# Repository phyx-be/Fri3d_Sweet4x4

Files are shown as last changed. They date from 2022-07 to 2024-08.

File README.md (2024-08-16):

# Sweet4x4 REV02

[Manual on how to assemble can be found here](https://fri3dcamp.github.io/badge_2024/sweet4x4/) Revision `02` no longer requires the Fri3d badge but instead relies solely on the us of a [TNY, QT Py or XIAO board](https://github.com/adafruit/awesome-qt-py). For future workshops we plan to use the [LANA TNY](https://phyx.be/LANA_TNY/). The workshop during [Fri3d Camp](https://fri3d.be/) will be done with a XIAO RP2040. 

## Firmare
LANA_TNY firmware is still underway.
For the Fri3d Camp workshop we opted for RP2040. An example using [KMK](https://kmkfw.io/) can be found in this repository.

There is an issue with the LEDs, when pushed too far in the footprint they tend to break. In order to prevent damaging the LEDs we sugges mounting only 6 on the bottom and use them for underglow.

Fully Assembled board with keycaps and case

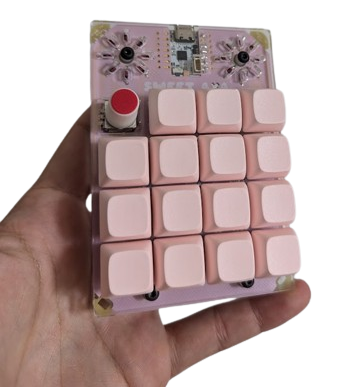
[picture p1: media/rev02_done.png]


# Fri3d_Sweet4x4 REV01

## About
The progress and more details about this project can be found on [Hackaday.io](https://hackaday.io/project/186574-sweet-4x4)

This PCB has, besides the required layout for a 4x4 keypad, some nifty features which will help during assembly and maintenance. The left most corner contains a diode bending corner, making sure that your diodes have their leads bent in the right spot will help during assembly. The other useful feature if a built in lube station. The X cutout will snugly fit a stem whilst the rectangular hole will  fit the body the switch you're cleaning.

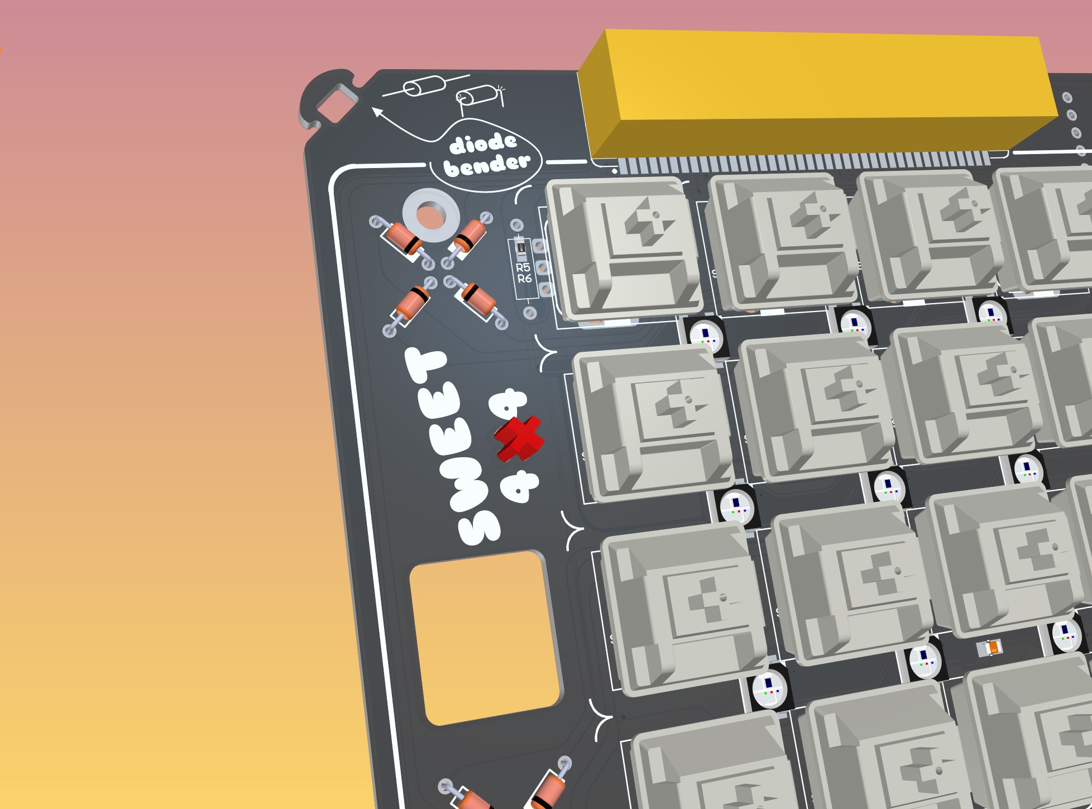
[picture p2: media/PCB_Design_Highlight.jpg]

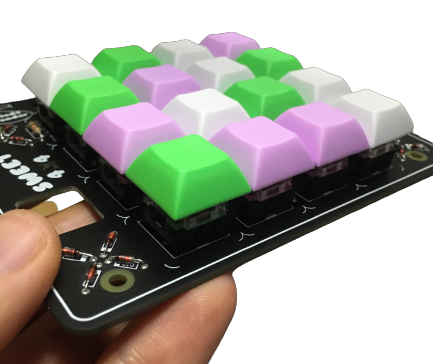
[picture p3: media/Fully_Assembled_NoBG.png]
Fully Assembled board with keycaps

Fully Assembled board with keycaps

## Getting started
### Using the Fri3d Camp 2022 badge
The Fri3d Badge has an ESP32 on board, because of the chip the badge uses we can only create a 4x4 Bluetooth keyboard.
1. Make sure you have Arduino IDE installed
2. Add the ESP32 board to the Arduino board manager, I think this link works well : https://randomnerdtutorials.com/installing-the-esp32-board-in-arduino-ide-windows-instructions/
3. Add the libraries you need
  - BLEKeyboard : https://github.com/T-vK/ESP32-BLE-Keyboard
  - Keypad : https://github.com/Chris--A/Keypad
  - Badge2020 : https://github.com/Fri3dCamp/Badge2020_arduino
  - Neopixel : https://github.com/adafruit/Adafruit_NeoPixel
4. Open the Sweet_4x4_minimal.ino code in the Arduino IDE, this only includes code to turn the pcb + badge into a BLE keyboard (not using screen or RGB leds)
5. Optionally you can use the Sweet_4x4_full.ino code, this also include some basic code to get the TFT screen to work

### Using a XIAO module
This allows to use the 4x4 PCB as a HID device over USB-C
Updating soon

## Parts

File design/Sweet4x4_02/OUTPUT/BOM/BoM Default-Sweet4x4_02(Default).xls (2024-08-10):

Bill of Materials |  |  | Sweet 4x4
Project: |  | Sweet4x4_02.PrjPcb
Revision: |  | 02
Variant: |  | Default
Creation Date: | 21/06/2024 | 14:10
Print Date: | 2024-06-21 | 14:10:08
Footprint | Comment | LibRef | Designator | Value | Description | Supplier 1 | Supplier Part Number 1 | Supplier 2 | Supplier Part Number 2 | Supplier 3 | Supplier Part Number 3 | Quantity
C_5.08mm |  | CAP 100nF 50V 5.08mm | C3, C4, C5 | 100nF 50V | CAP 100nF 50V 5.08mm | LCSC | C84772 |  |  |  |  | 3
DO-35 | 1N4148 100V 200mA 1Vf@10mA | DIO 1N4148 DO-35 | D1, D2, D3, D4, D5, D6, D7, D8, D9, D10, D11, D12, D13, D14, D15, D16 | 1N4148 | DIO 1N4148 DO-35 | LCSC | C14538 | LCSC | C14516 |  |  | 16
LED_5mm_RGB_RECT_EASY | WS2812 based digital RGB LED 5mm Rectangle | LED RGB WS2812 5mm Rectangle | D17, D18, D19, D20, D21, D22, D23, D24, D25 | WS2812D-255 | LED RGB WS2812 5mm Rectangle | LCSC | C4154874 |  |  |  |  | 9
PHYX_LANA_TNY_SMD | CH23V203 based TNY module | MOD # CH23V203 LANA TNY SMD | MOD1 | LANA TNY | MOD # CH23V203 LANA TNY SMD | Phyx | LANA TNY |  |  |  |  | 1
Cherry_MX1A | Cherry MX Blue | SW Cherry MX1A-E1NN Blue | SW1, SW2, SW3, SW4, SW5, SW6, SW7, SW8, SW9, SW10, SW11, SW12, SW13, SW14, SW15, SW16 | MX1A-E1NN | SW Cherry MX1A-E1NN Blue | Digi-key | CH196-ND | Mouser | 540-MX1A-E1NN |  |  | 16
 |  |  |  |  |  |  |  |  |  |  |  | 45
Approved |  | Notes

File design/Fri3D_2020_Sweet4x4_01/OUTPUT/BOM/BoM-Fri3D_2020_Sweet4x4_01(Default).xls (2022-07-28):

Bill of Materials |  |  | Fri3D 2020 Sweet 4x4
Project: |  | Fri3D_2020_Sweet4x4_01.PrjPcb
Revision: |  | 01
Variant: |  | Default
Creation Date: | 07/06/2022 | 22:18
Print Date: | 2022-06-07 | 22:18:32
Footprint | Comment | LibRef | Designator | Value | Description | Supplier 1 | Supplier Part Number 1 | Supplier 2 | Supplier Part Number 2 | Supplier 3 | Supplier Part Number 3 | Quantity
C0805_N |  | CAP # 10uF 10V 0805 | C1 | 10uF 10V | CAP # 10uF 10V 0805 | Farnell | 2320859 | LCSC | C17024 | Generic | 10uF 10V 0805 X7R | 1
DO-35 | 1N4148 100V 200mA 1Vf@10mA | DIO 1N4148 DO-35 | D1, D2, D3, D4, D5, D6, D7, D8, D9, D10, D11, D12, D13, D14, D15, D16 | 1N4148 | DIO 1N4148 DO-35 | LCSC | C14538 | LCSC | C14516 |  |  | 16
LED_5050_WS2812B_BLACK | WS2812 based digital RGB LED 5050 Black package | LED # RGB WS2812B-5050 BL | D17, D18, D19, D20, D21, D22, D23, D24, D25 | WS218B 5050 BL | LED # RGB WS2812B-5050 BL | Aliexpress | WS2812B Black 5050 | LCSC | C114586 |  |  | 9
MicroBIT_CYLCONN_SMD_180 | MicroBit 180deg connector Cylconn | MicroBit # Cylconn | P2 |  | MicroBit # Cylconn | TaoBao |  |  |  |  |  | 1
R0603_N |  | RES # 10K 0603 | R1, R3, R5 | 10K | RES # 10K 0603 | Farnell | 2502397 | LCSC | C25804 | Generic | 10K 1% 0603 | 3
Cherry_MX1A | Cherry MX Blue | SW Cherry MX1A-E1NN Blue | SW1, SW2, SW3, SW4, SW5, SW6, SW7, SW8, SW9, SW10, SW11, SW12, SW13, SW14, SW15, SW16 | MX1A-E1NN | SW Cherry MX1A-E1NN Blue | Digi-key | CH196-ND | Mouser | 540-MX1A-E1NN |  |  | 16
TP_1.5mm_0.9mm |  | TP 1.5mm | TP1, TP2, TP3, TP4, TP5, TP6, TP7, TP8, TP9, TP10, TP11, TP12, TP13 | NO BOM | TP 1.5mm |  |  |  |  |  |  | 13
 |  |  |  |  |  |  |  |  |  |  |  | 59
Approved |  | Notes

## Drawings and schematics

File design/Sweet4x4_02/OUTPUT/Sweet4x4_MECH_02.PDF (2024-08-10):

## Sweet 4x4 Mechanical drawings

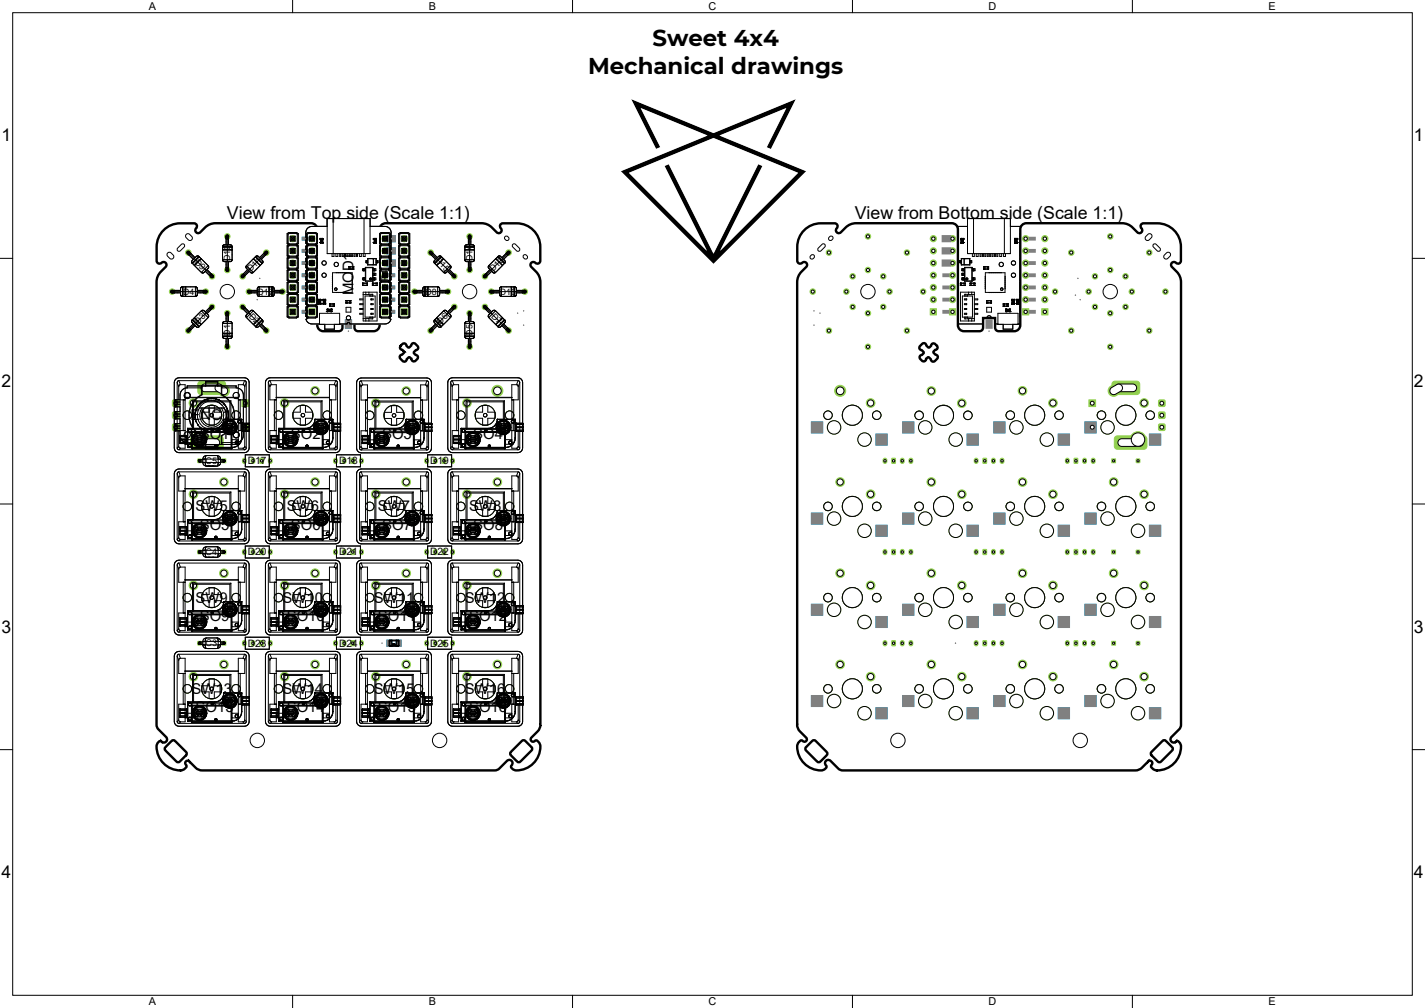
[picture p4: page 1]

## Sweet 4x4 Silkscreen

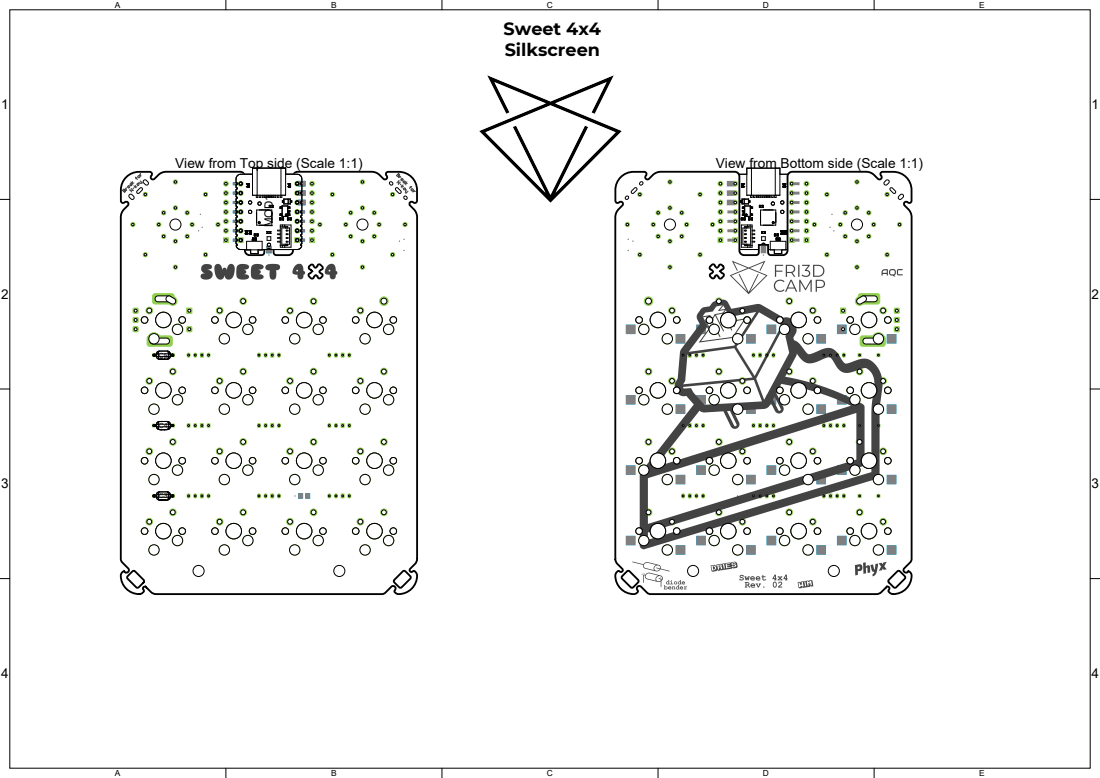
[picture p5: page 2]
MOD1

View from Top side (Scale 1:1)

View from Bottom side (Scale 1:1)

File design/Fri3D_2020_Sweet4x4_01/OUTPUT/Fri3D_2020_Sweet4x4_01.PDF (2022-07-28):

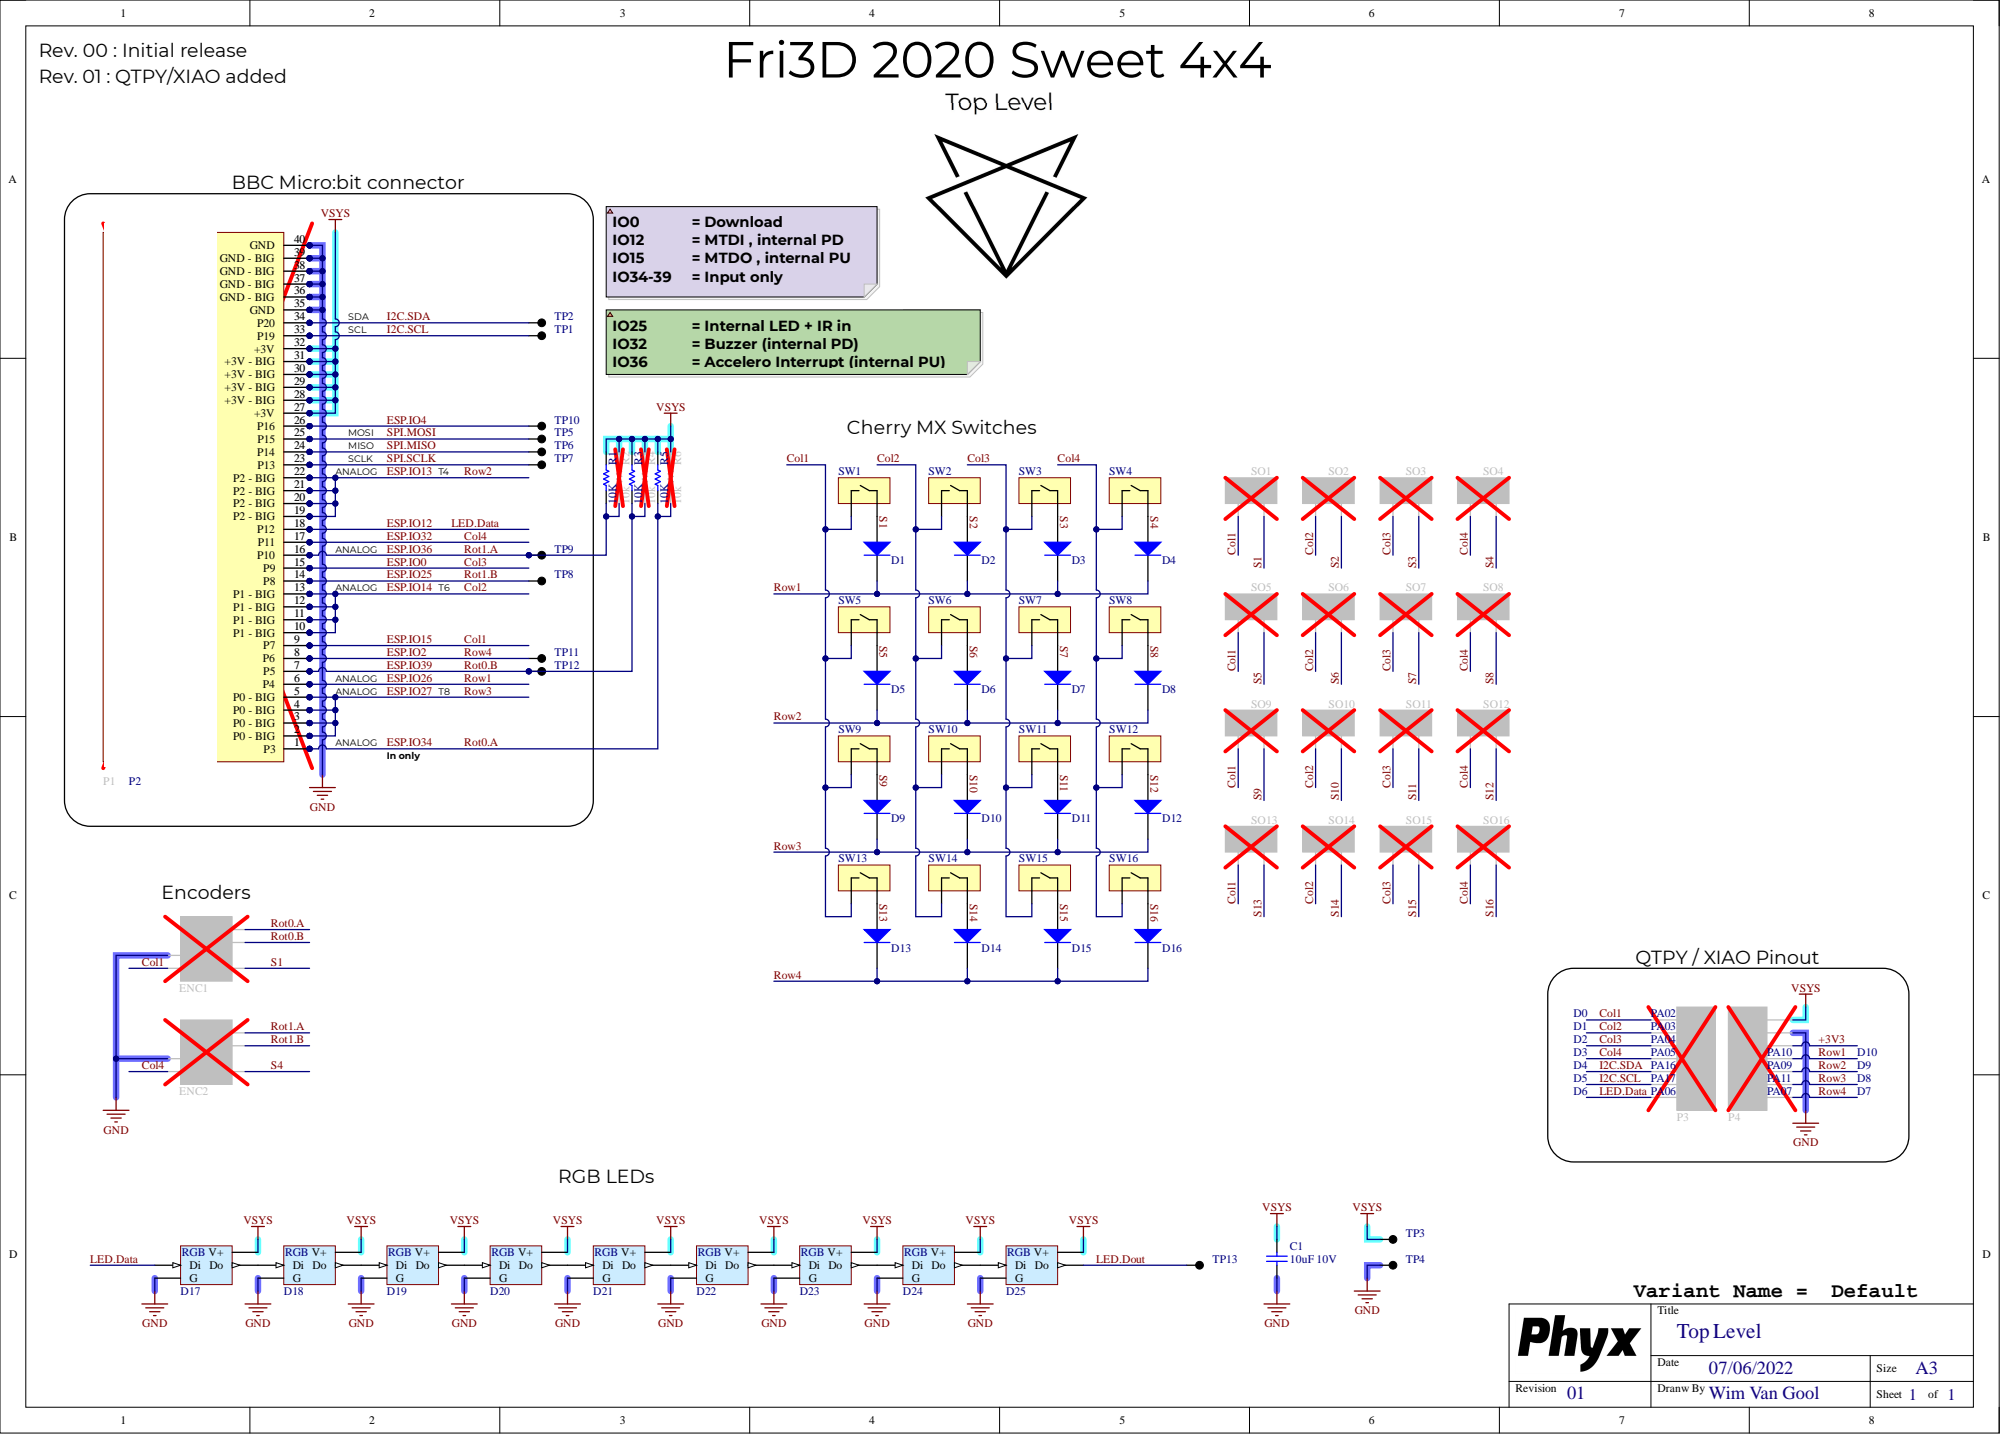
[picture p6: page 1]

Rev. 00 : Initial release
Rev. 01 : QTPY/XIAO added

BBC Micro:bit connector

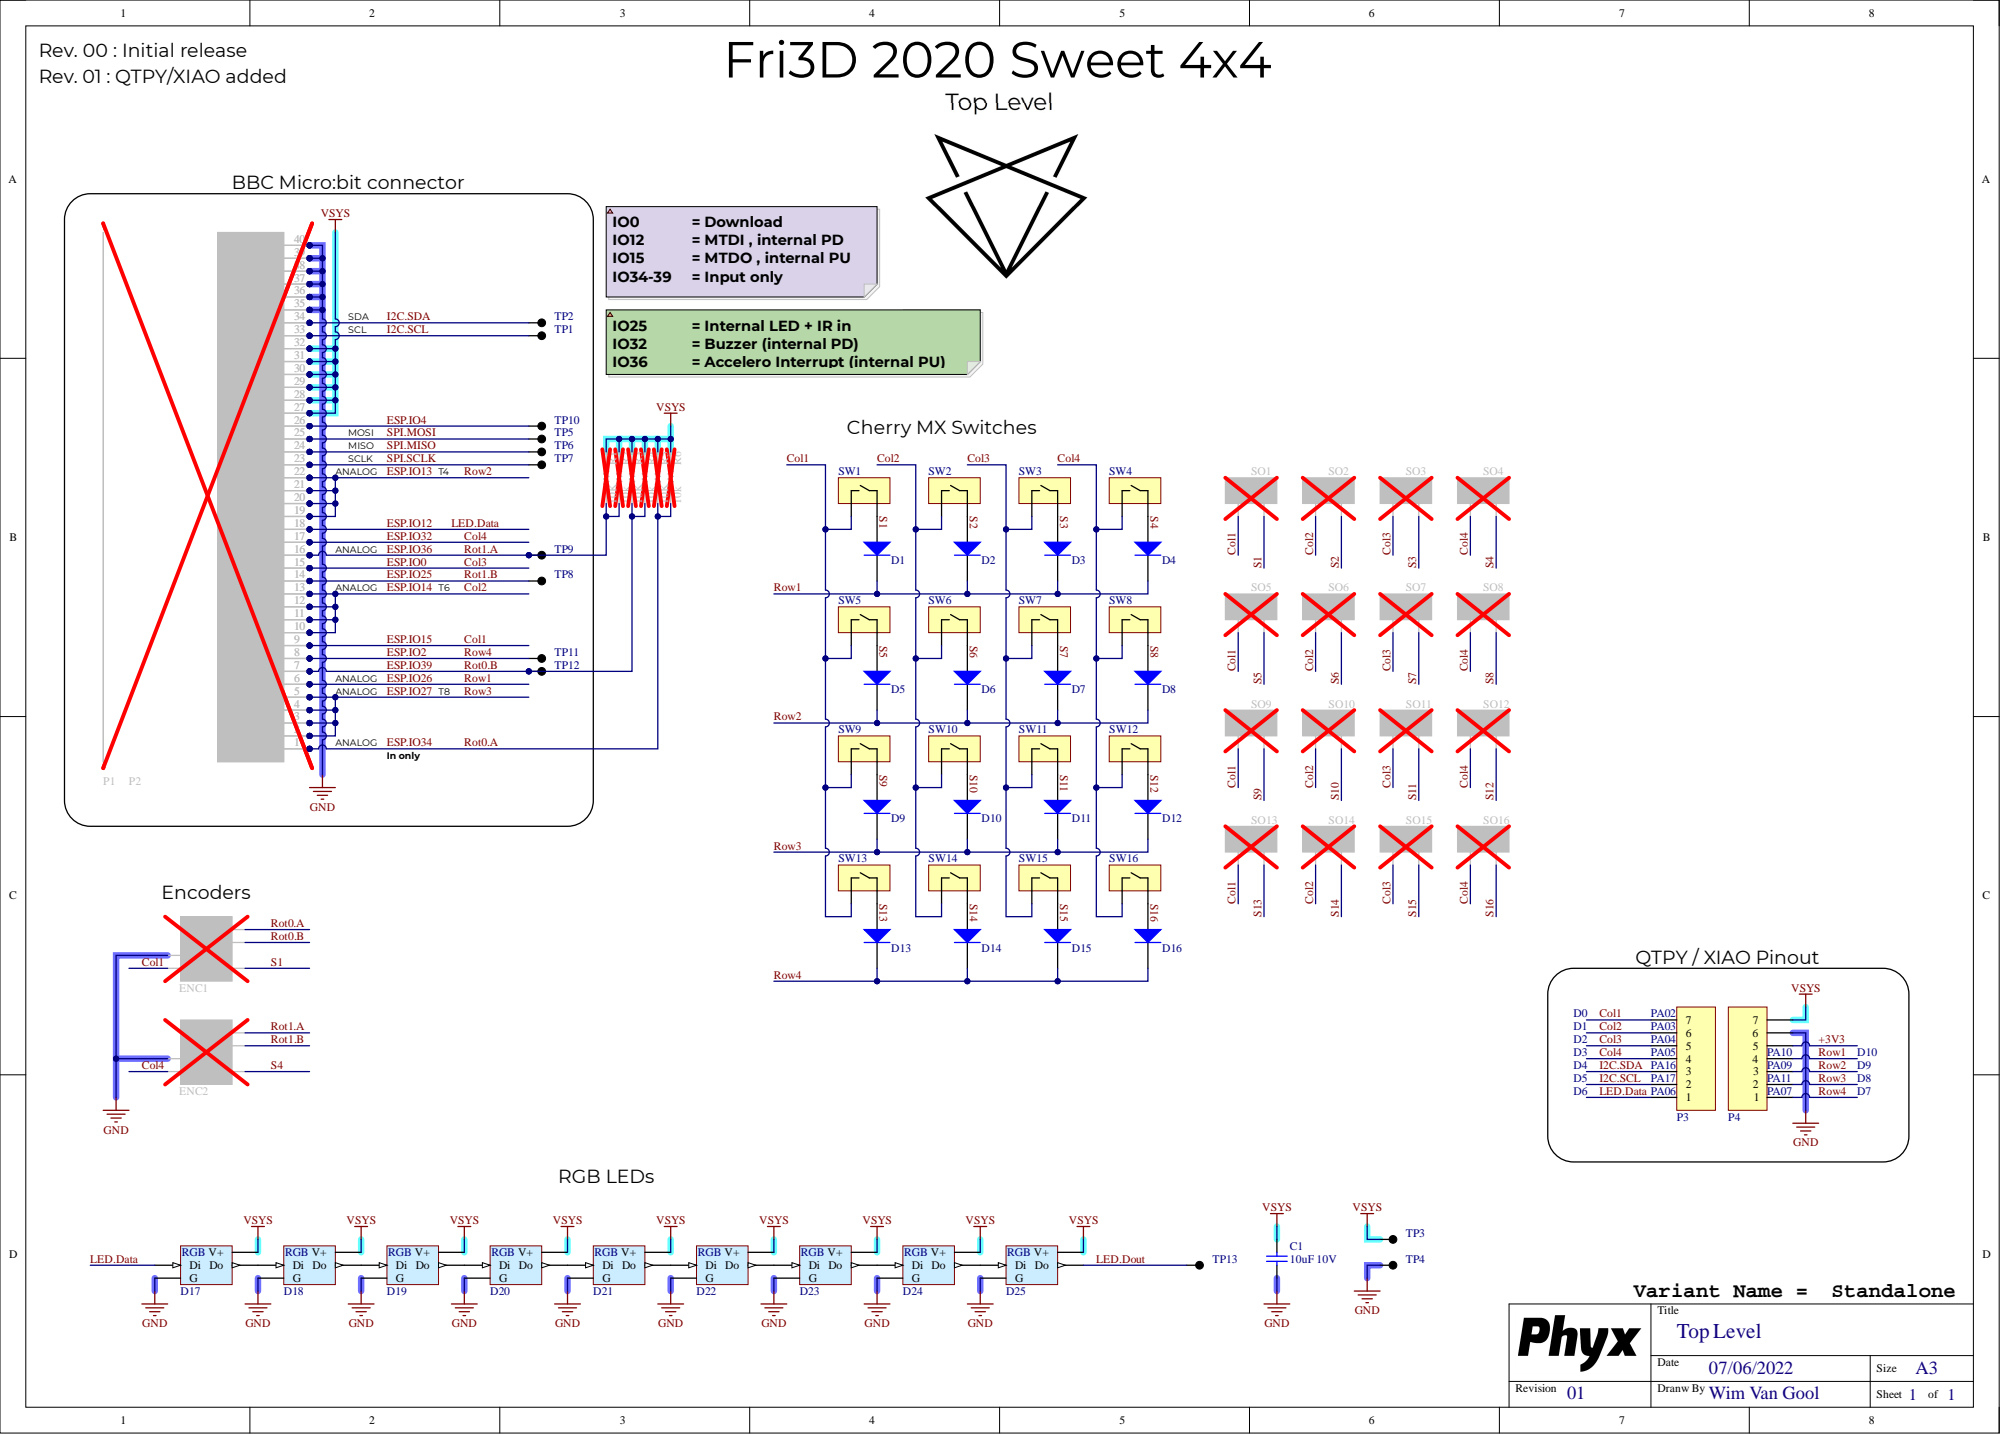
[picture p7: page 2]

Rev. 00 : Initial release
Rev. 01 : QTPY/XIAO added

BBC Micro:bit connector

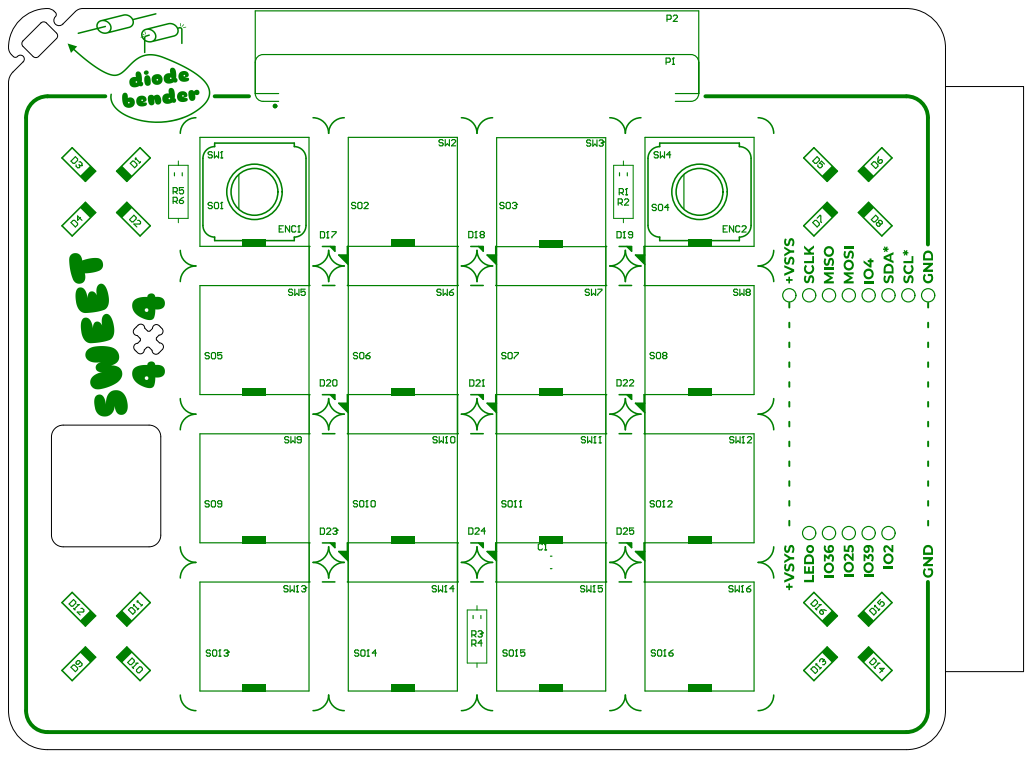
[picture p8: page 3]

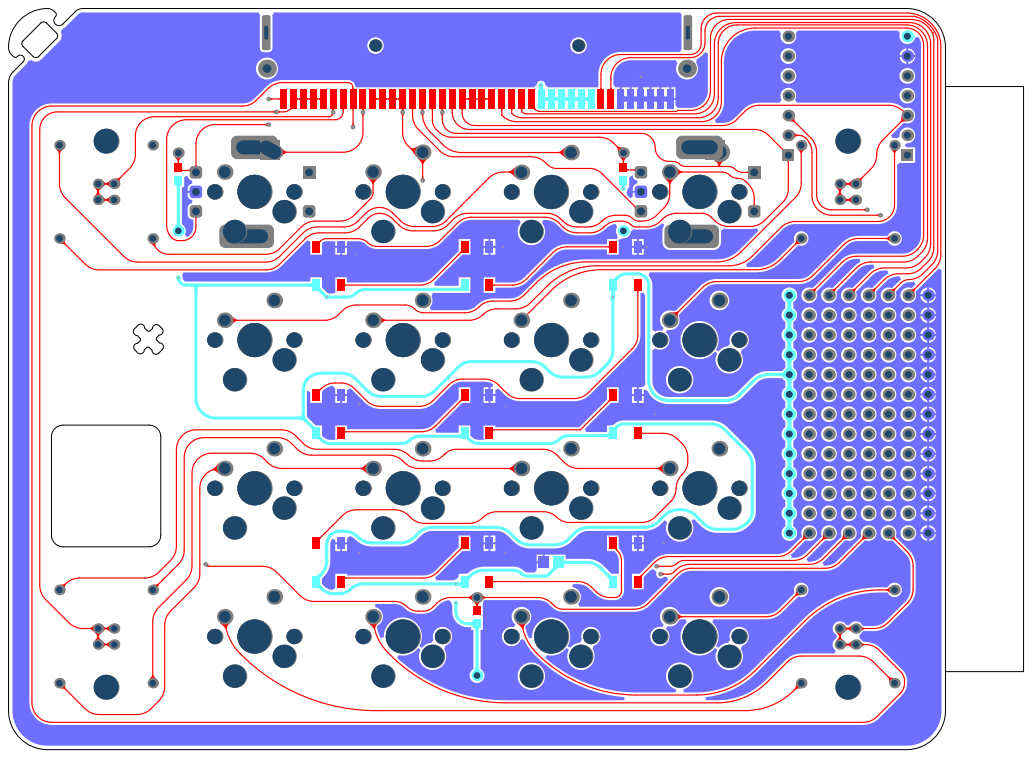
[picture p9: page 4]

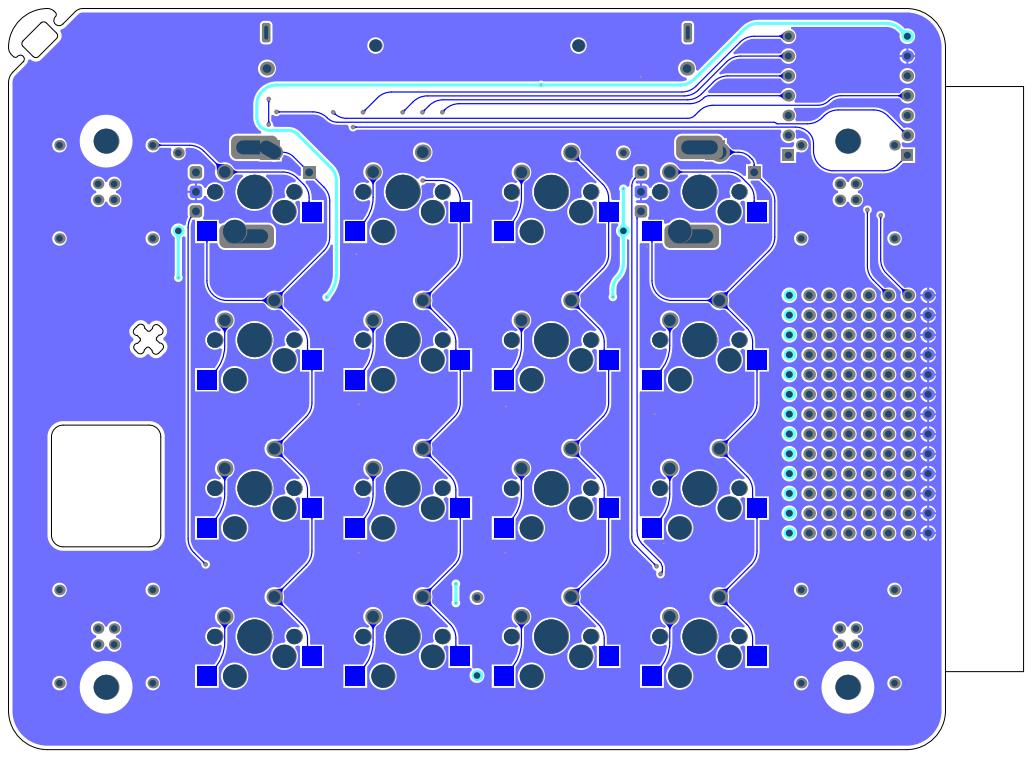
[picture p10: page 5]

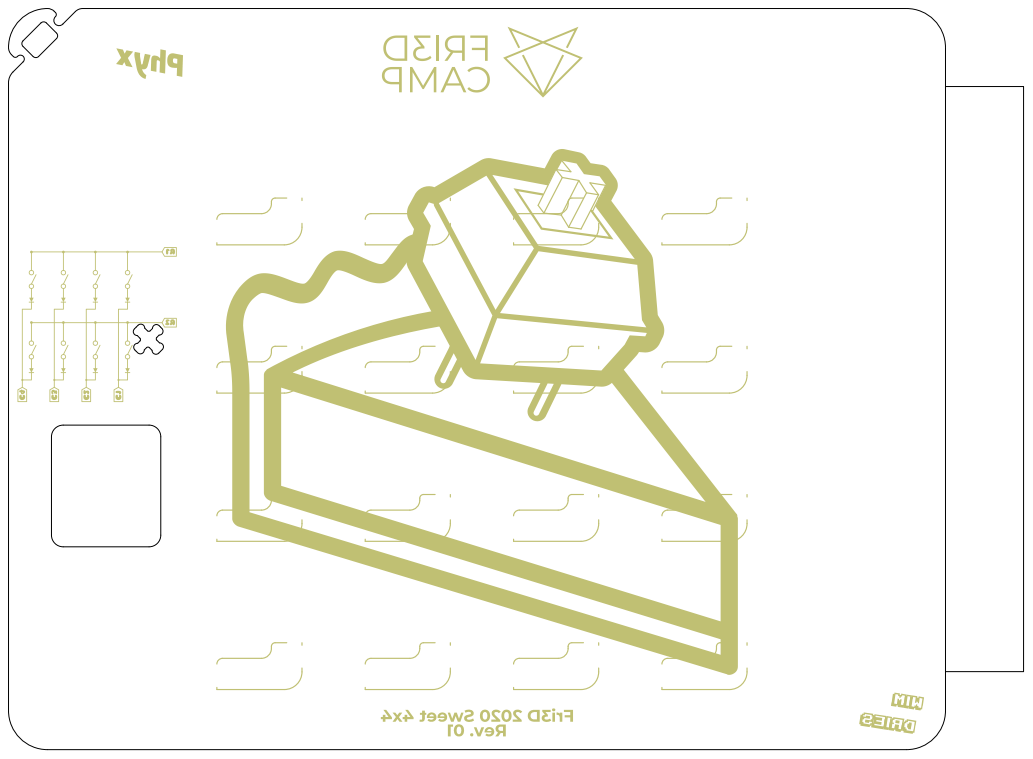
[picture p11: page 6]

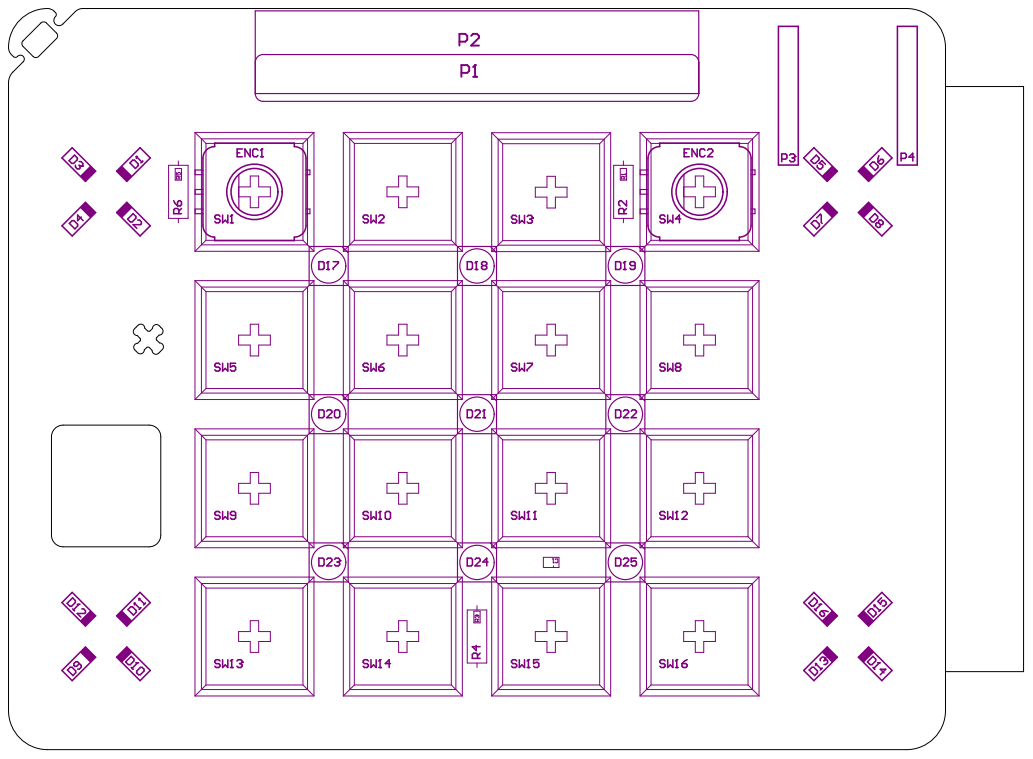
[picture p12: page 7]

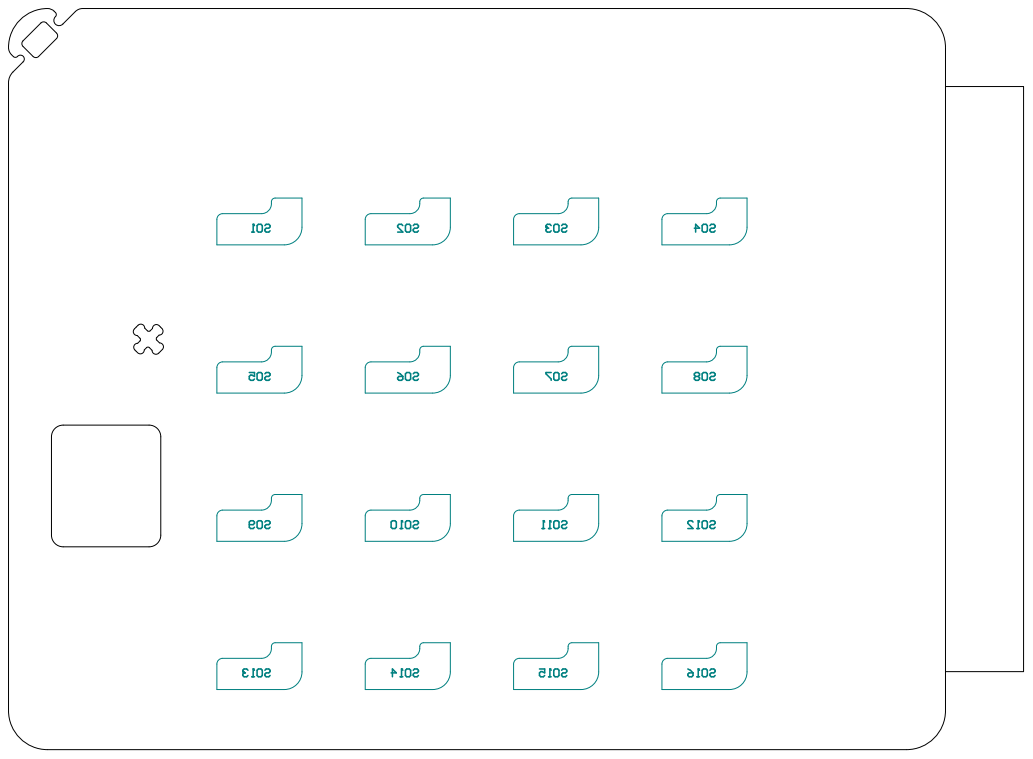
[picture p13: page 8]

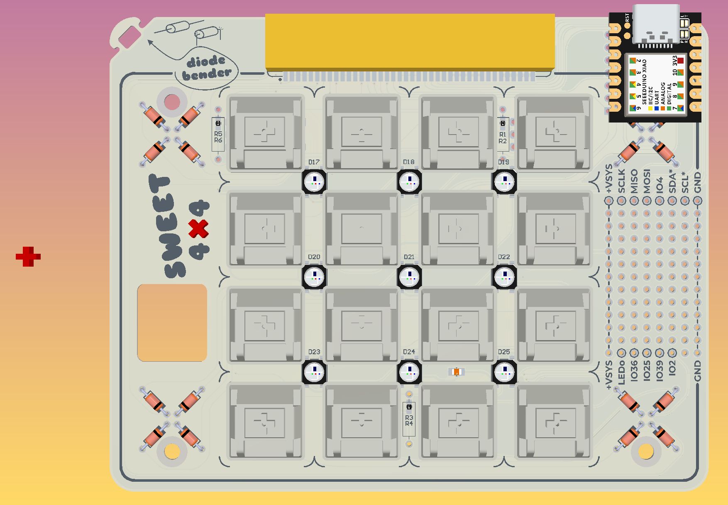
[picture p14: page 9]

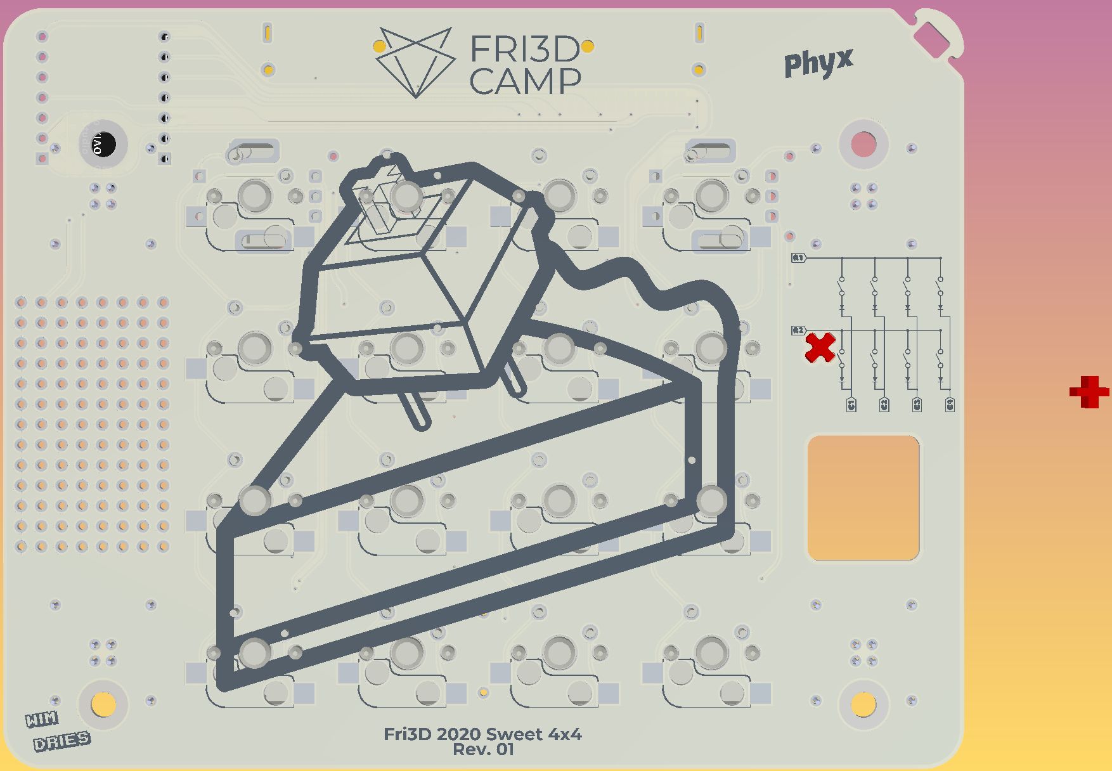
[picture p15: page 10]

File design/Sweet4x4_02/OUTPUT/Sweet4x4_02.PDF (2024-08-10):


Rev. 00 : Initial release
Rev. 01 : QTPY/XIAO added
Rev. 02 : Standalone only


Rev. 00 : Initial release
Rev. 01 : QTPY/XIAO added
Rev. 02 : Standalone only









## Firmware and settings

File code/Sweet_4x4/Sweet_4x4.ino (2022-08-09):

// This code is for the sweet 4x4 badge addon
#include <Adafruit_NeoPixel.h>
#include <Badge2020_TFT.h>
Badge2020_TFT tft;

#include <BleKeyboard.h>
// This library is for using BLE HID with your ESP32
// 
// This is not availble on the library manager so
// needs to be installed from Github
// https://github.com/T-vK/ESP32-BLE-Keyboard

#include <Keypad.h>
// This library is for interfacing with the 4x4 Matrix
// 
// Can be installed from the library manager, search for "keypad"
// and install the one by Mark Stanley and Alexander Brevig
// https://playground.arduino.cc/Code/Keypad/ - https://github.com/Chris--A/Keypad

const byte ROWS = 4; //four rows
const byte COLS = 4; //four columns

// the library will return the character inside this array
// when the appropriate button is pressed.
char keys[ROWS][COLS] = {
  {'1', '2', '3', 'A'}, 
  {'4', '5', '6', 'B'}, 
  {'7', '8', '9', 'C'}, 
  {'*', '0', '#', 'D'}, 
};

// Because our Fri3d macropad is wired in row2col we need to change rows and columns around

byte colPins[ROWS] = {26,13,27,2}; //connect the column pinouts to the rows of the keypad
byte rowPins[COLS] = {15,14,0,32}; //connect the row pinouts to the columns of the keypad

Keypad keypad = Keypad( makeKeymap(keys), rowPins, colPins, ROWS, COLS );

// First param is name
// Second is manufacturer
// Third is initial battery level
BleKeyboard bleKeyboard("Sweet4x4", "Fri3d", 100);

#define LEDPIN 12
#define LEDPIN_INT 2
#define NUMPIXELS 9
#define NUMPIXELS_INT 5

Adafruit_NeoPixel strip(NUMPIXELS, LEDPIN, NEO_GRB + NEO_KHZ800);
Adafruit_NeoPixel strip_int(NUMPIXELS, LEDPIN_INT, NEO_GRB + NEO_KHZ800);
uint32_t warmwhite = strip.Color(255, 191, 0);

void setup() {
 // Serial.begin(9600);
  bleKeyboard.begin();
  pinMode (0, OUTPUT);
  strip.begin(); // INITIALIZE NeoPixel strip object (REQUIRED)
  strip_int.begin(); // INITIALIZE NeoPixel strip object (REQUIRED)
  strip.setBrightness(10);
  strip_int.setBrightness(10);

  tft.init(240, 240);
  tft.setRotation( 2 );

  pinMode( BADGE2020_BACKLIGHT, OUTPUT );
  digitalWrite( BADGE2020_BACKLIGHT, HIGH );

  // Anything from the Adafruit GFX library can go here, see
  // https://learn.adafruit.com/adafruit-gfx-graphics-library
  
  tft.fillScreen(ST77XX_BLACK);
  tft.setCursor(10, 110);
  tft.setTextColor(ST77XX_WHITE);
  tft.setTextSize(3);
  tft.println("The cake is a lie");
  
}

// This will hold down all the following buttons.
void sendMacroCommand(uint8_t key) {
  bleKeyboard.press(key);
}

void loop() {
strip.fill(warmwhite, 0, 9);
strip.show();

for(int i=0; i<5; i++) { // For each pixel...
    strip_int.setPixelColor(i, strip_int.Color(0, 150, 0));
    strip_int.show();
}

  char key = keypad.getKey();

  // Only do something with the keypress if we
  // are connected to something via bluetooth
  
 if (bleKeyboard.isConnected() && key) {
   // Serial.println(key);
    switch (key) {
      case '1':
        sendMacroCommand('1');
        break;
      case '2':
        sendMacroCommand('2');
        break;
      case '3':
        sendMacroCommand('3');
        break;
      case '4':
        sendMacroCommand('4');
        break;
      case '5':
        sendMacroCommand('5');
        break;
      case '6':
        sendMacroCommand('6');
        break;
      case '7':
        sendMacroCommand('7');
        break;
      case '8':
        sendMacroCommand('8');
        break;
      case '9':
        sendMacroCommand('9');
        break;
      case '0':
        sendMacroCommand('0');
        break;
      case '*':
        sendMacroCommand('a');
        break;
      case '#':
        sendMacroCommand('b');
        break;
      case 'A':
        sendMacroCommand('c');
        break;
      case 'B':
        sendMacroCommand('d');
        break;
      case 'C':
        sendMacroCommand('e');
        break;
      case 'D':
        sendMacroCommand('f');
        break;
    }
    //delay(50);
    bleKeyboard.releaseAll(); // this releases the buttons
   }
}

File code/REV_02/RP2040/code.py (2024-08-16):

import board

from kmk.kmk_keyboard import KMKKeyboard
from kmk.keys import KC
from kmk.scanners import DiodeOrientation
from kmk.extensions.rgb import RGB
from kmk.extensions.media_keys import MediaKeys
from kmk.modules.layers import Layers
from kmk.modules.encoder import EncoderHandler

# Rotary

keyboard = KMKKeyboard()

keyboard.col_pins = (board.D0, board.D1, board.D2, board.D3)
keyboard.row_pins = (board.D10, board.D7, board.D8, board.D9)
keyboard.diode_orientation = DiodeOrientation.ROW2COL

# LEDs + colour on layer change
# Based on https://kmkfw.io/layers/#active-layer-indication-with-rgb

class LayerRGB(RGB):
    def on_layer_change(self, layer):
        print(f"Changing to layer {layer}")
        if layer == 0:
            self.set_hsv_fill(0, self.sat_default, self.val_default)   # red
        elif layer == 1:
            self.set_hsv_fill(170, self.sat_default, self.val_default) # blue
        elif layer == 2:
            self.set_hsv_fill(43, self.sat_default, self.val_default)  # yellow
        RGB.show()

RGB = LayerRGB(pixel_pin=board.D6, # GPIO pin of the status LED, or background RGB light
        num_pixels=9,                # one if status LED, more if background RGB light
        rgb_order=(1, 0, 2),         # RGB order may differ depending on the hardware
        hue_default=100,               # in range 0-255: 0/255-red, 85-green, 170-blue
        sat_default=255,
        val_default=10,
        )

keyboard.extensions.append(RGB)

class RGBLayers(Layers):
    def activate_layer(self, keyboard, layer, idx=None):
        super().activate_layer(keyboard, layer, idx)
        RGB.on_layer_change(layer)
        RGB.show()

    def deactivate_layer(self, keyboard, layer):
        super().deactivate_layer(keyboard, layer)
        RGB.on_layer_change(keyboard.active_layers[0])
        RGB.show()

keyboard.modules.append(RGBLayers())

# Rotary Encoder
# https://github.com/KMKfw/kmk_firmware/blob/master/docs/en/encoder.md

keyboard.extensions.append(MediaKeys())

encoder_handler = EncoderHandler()
keyboard.modules.append(encoder_handler)
encoder_handler.pins = (
    (board.D4, board.D5, None,), # encoder #1 
    )

encoder_handler.map = [ (( KC.VOLU, KC.VOLD, None), )]

keyboard.keymap = [
    [KC.N1,KC.N2,KC.N3,KC.N4,
     KC.N5,KC.N6,KC.N7,KC.N8,
     KC.A,KC.B,KC.C,KC.D,
     KC.RGB_TOG,KC.RGB_HUI,KC.RGB_HUD,KC.RGB_MODE_KNIGHT,
     ]
]

# For all keypresses check : https://kmkfw.io/keycodes/
# For RGB stuff check : https://kmkfw.io/rgb/

if __name__ == '__main__':
    keyboard.go()

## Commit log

2022-08-08 added basic example for screen, on badge leds and on macropad leds
2024-08-10 Sweet 4x4 REV 02 files added
    [BoM Default-Sweet4x4_02(Default).xls, BoM Encoder-Sweet4x4_02(Encoder).xls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]
